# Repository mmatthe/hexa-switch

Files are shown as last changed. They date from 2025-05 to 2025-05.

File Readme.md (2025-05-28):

# HexaSwitch - 6-Channel Switch for Tasmota

This project is a custom-designed printed circuit board (PCB) for a Tasmota-compatible IoT device based on the ESP32 microcontroller. It allows switching of **6 loads**, with each channel capable of handling up to **2 Amps**. The device contains a real-time clock such that the device can also run on an independent time base. 

<p float="left">
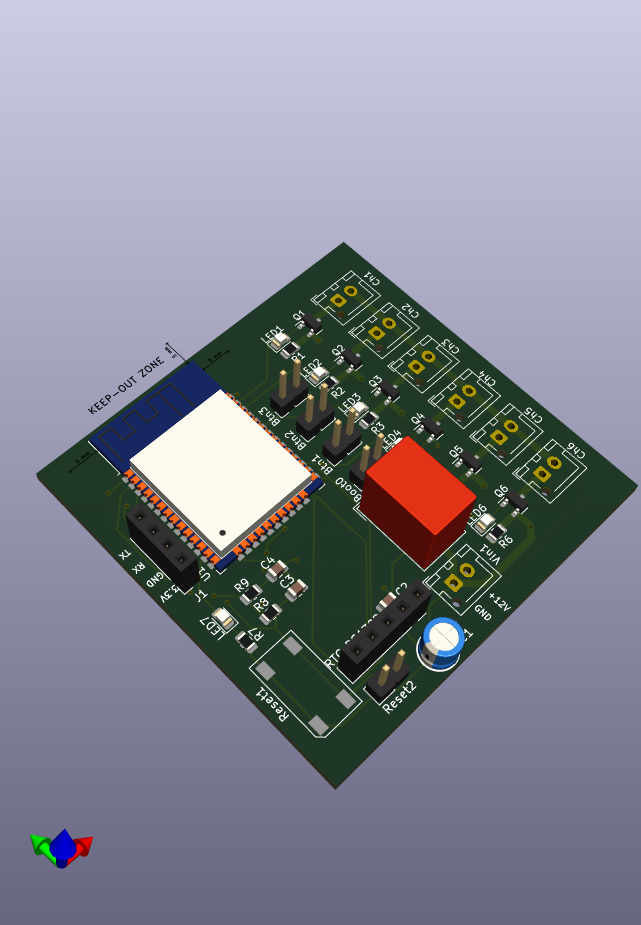
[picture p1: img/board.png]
   
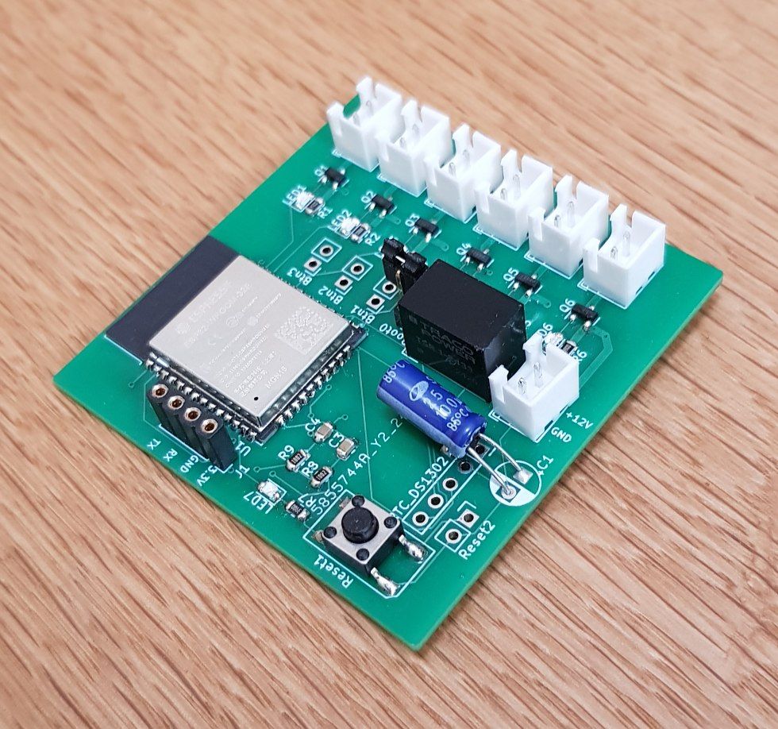
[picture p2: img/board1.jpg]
  
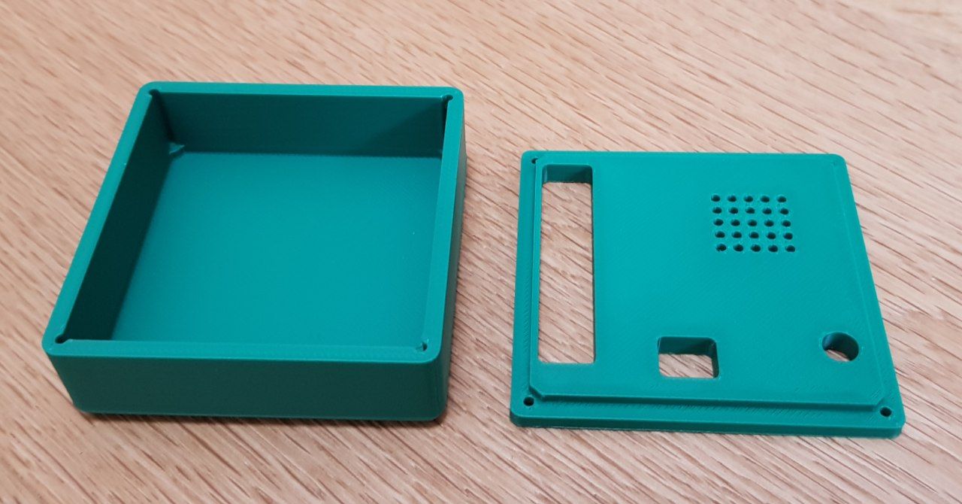
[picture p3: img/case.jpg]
   
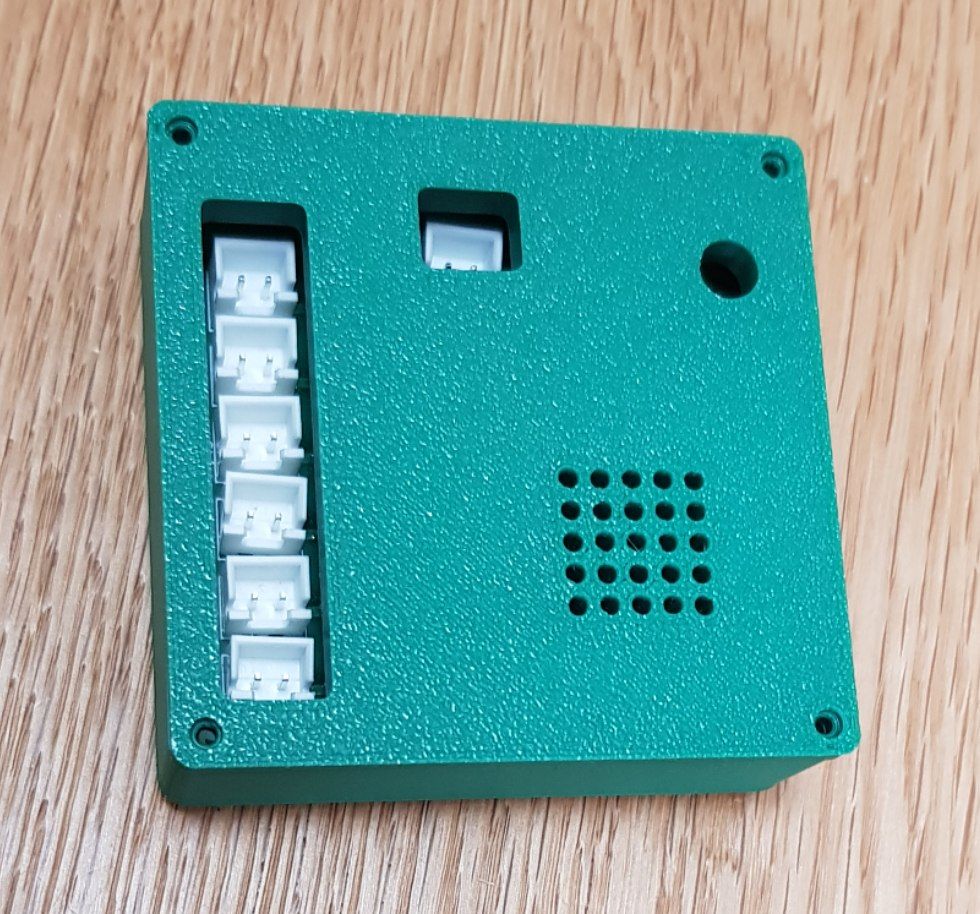
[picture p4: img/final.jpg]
   
</p>

I use it for switching on and off 12V valves for watering plants in the garden. It can also be used to switch relays and contactors to switch larger powers. 

---

## Features

- Link to [Schematic](schematic/schematic.pdf) and [BOM](schematic/bom/ibom.html)
- **ESP32-based** controller compatible with [Tasmota firmware](https://tasmota.github.io/)
- **6 independent load switching channels** (up to 2A per channel)
- **3 digital inputs**
- Supports power input from **5V to 24V**
- Optional **Real-Time Clock (RTC)** connector (not required for operation)
- Custom PCB designed using **KiCad**

---

## Hardware Details

- Power Supply: 5–24V DC input
- Switching: 6 channels, each capable of switching loads up to 2A
- Inputs: 3 digital inputs
- Microcontroller: ESP32
- Optional RTC interface for time-sensitive automation

---

## Usage

1. Assemble the PCB and connect loads to the output channels.
2. Flash the ESP32 with [Tasmota firmware](https://tasmota.github.io/).
3. Power the device with a DC supply between 5V and 24V.
4. Use Tasmota’s web interface or MQTT to control each channel independently.

---

## License

This project is released under the MIT License.

---

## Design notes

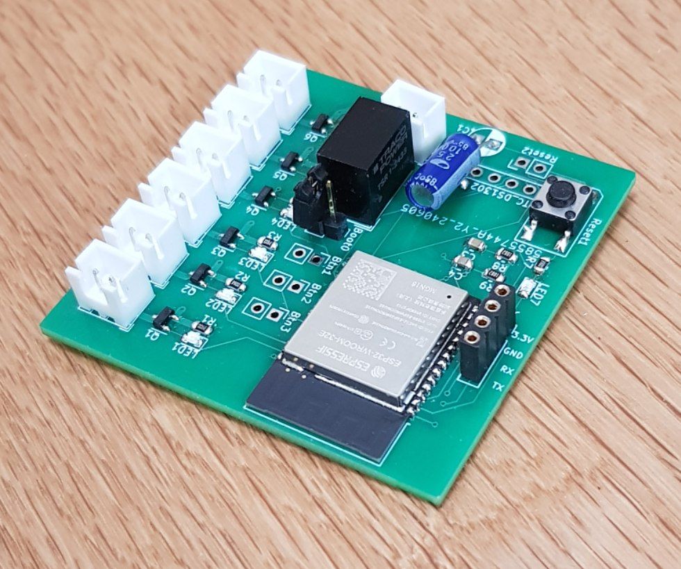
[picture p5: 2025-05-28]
img/board2.jpg

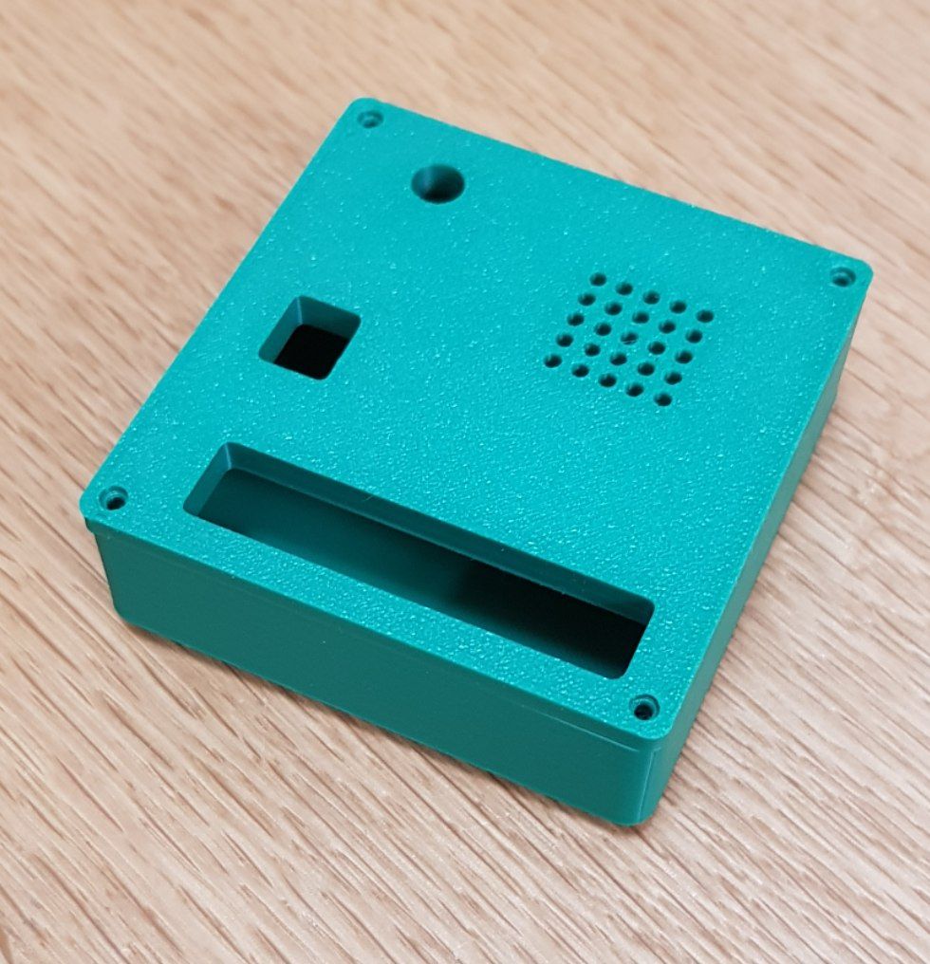
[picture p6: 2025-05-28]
img/final2.jpg

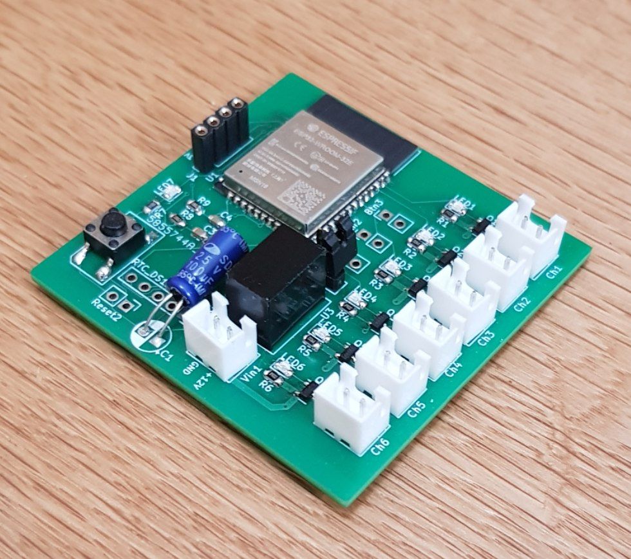
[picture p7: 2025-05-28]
img/board4.jpg

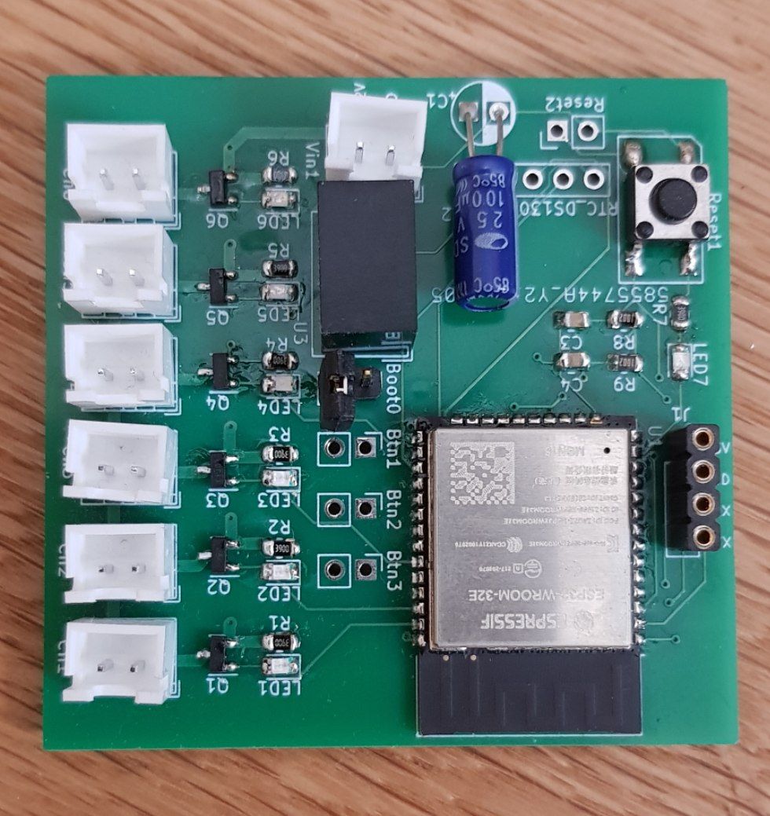
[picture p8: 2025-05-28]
img/board3.jpg

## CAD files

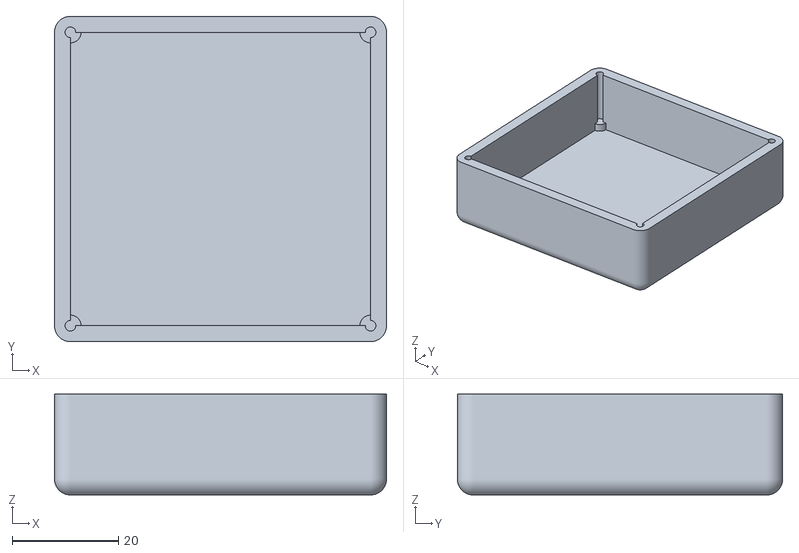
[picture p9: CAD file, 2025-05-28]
case/stl/bottom.stl
62.5 x 61.2 x 19.0

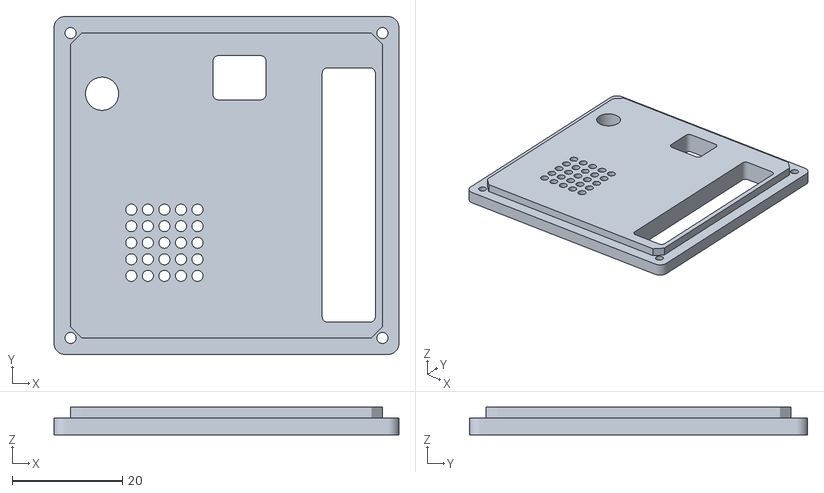
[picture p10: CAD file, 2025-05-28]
case/stl/top.stl
62.5 x 61.2 x 5.00

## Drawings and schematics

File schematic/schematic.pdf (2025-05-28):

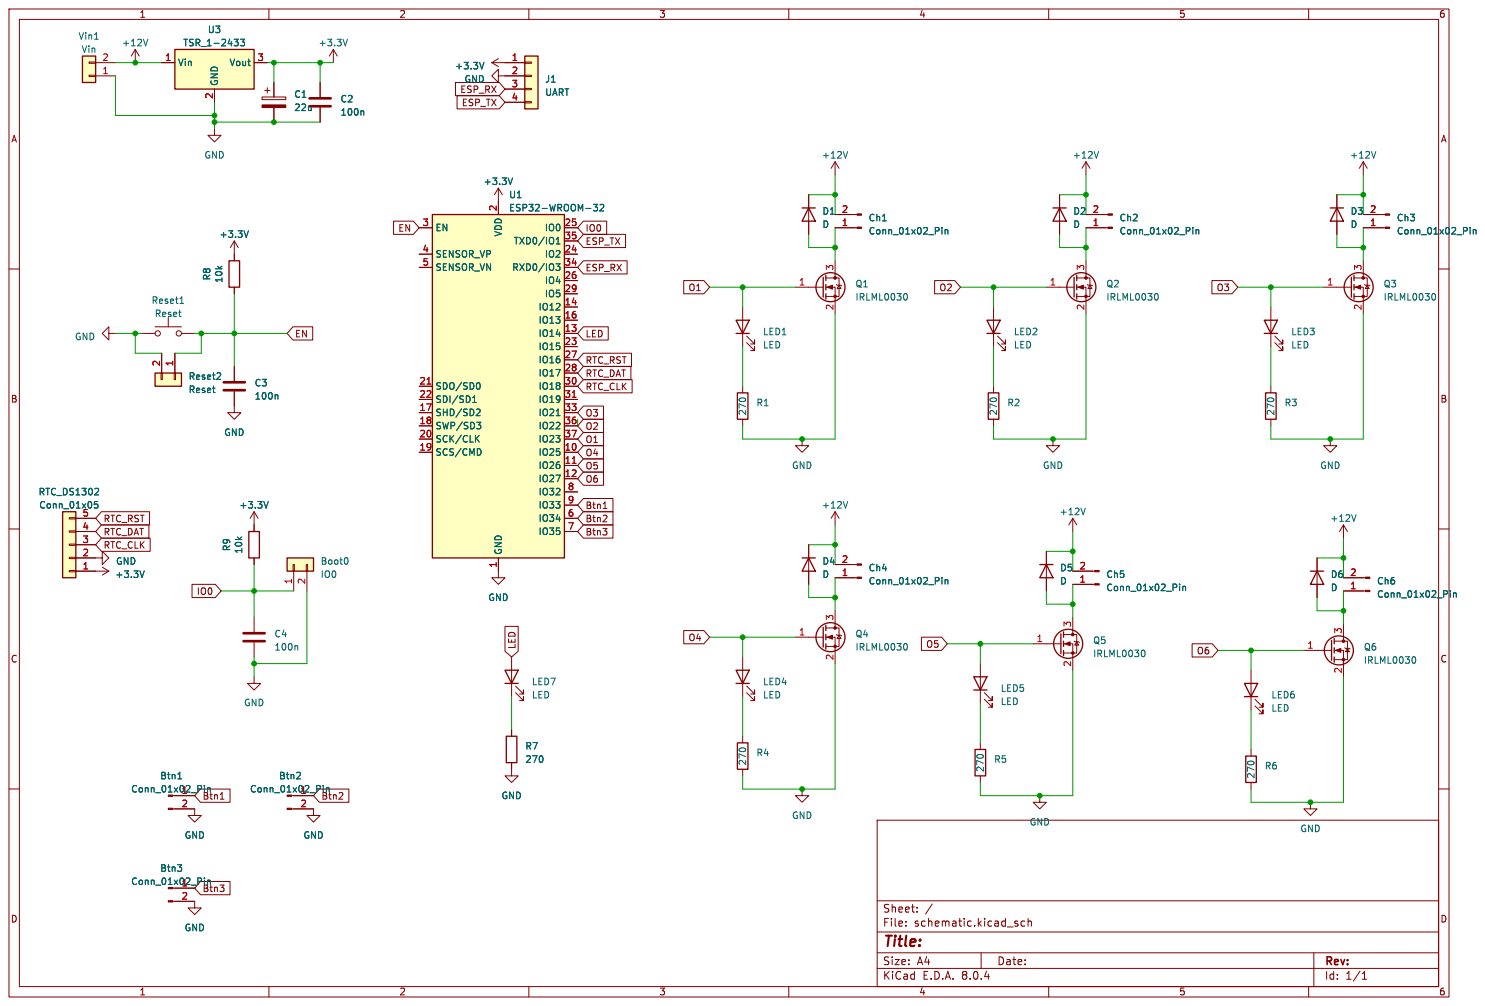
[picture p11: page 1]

2 SCK/CLK 20 SDO/SD0 21 SDI/SD1 22

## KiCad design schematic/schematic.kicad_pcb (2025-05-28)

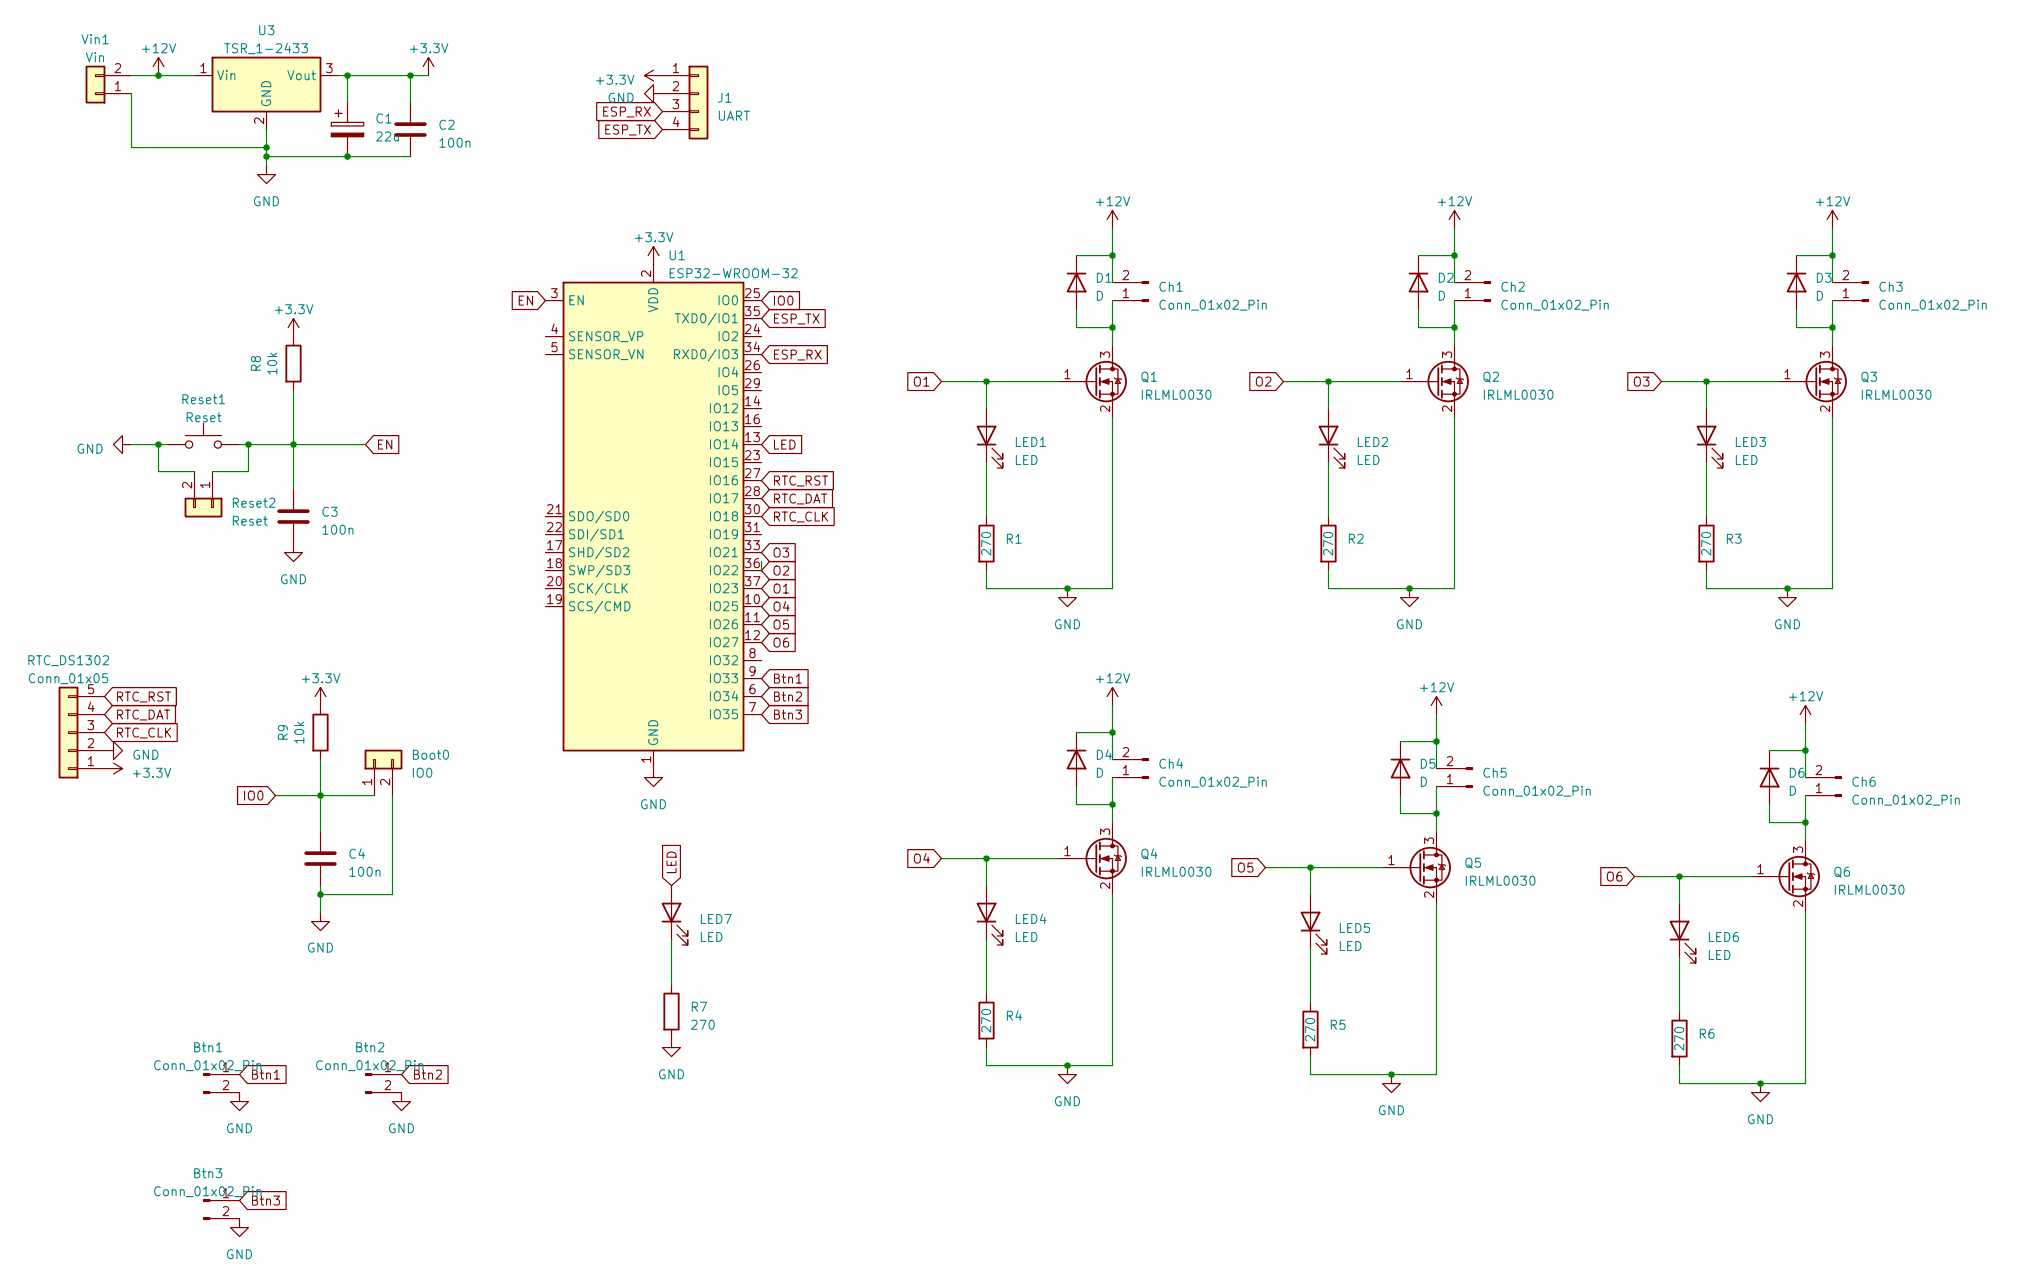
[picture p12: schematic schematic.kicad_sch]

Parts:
Boot0: IO0; PinHeader_1x02_P2.54mm_Vertical
Btn1, Btn2, Btn3: Conn_01x02_Pin; PinHeader_1x02_P2.54mm_Vertical
C1: 22u; CP_Radial_D5.0mm_P2.50mm
C2, C3, C4: 100n; C_0805_2012Metric
Ch1, Ch2, Ch3, Ch4, Ch5, Ch6: Conn_01x02_Pin; JST_XH_B2B-XH-AM_1x02_P2.50mm_Vertical
D1, D2, D3, D4, D5, D6: D; D_SOD-123
J1: UART; PinSocket_1x04_P2.54mm_Vertical
LED1, LED2, LED3, LED4, LED5, LED6, LED7: LED; LED_0805_2012Metric
Q1, Q2, Q3, Q4, Q5, Q6: IRLML0030; SOT-23
R1, R2, R3, R4, R5, R6, R7: 270; R_0805_2012Metric
R8, R9: 10k; R_0805_2012Metric
RTC_DS1302: Conn_01x05; PinSocket_1x05_P2.54mm_Vertical
Reset1: Reset; Reichelt 9315
Reset2: Reset; PinHeader_1x02_P2.54mm_Vertical
U1: ESP32-WROOM-32
U3: TSR_1-2433; Converter_DCDC_TRACO_TSR-1_THT
Vin1: Vin; JST_XH_B2B-XH-AM_1x02_P2.50mm_Vertical

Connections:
+3.3V: C1.1, C2.1, J1.1, R8.1, R9.1, RTC_DS1302.1, U1.2 (VDD), U3.3 (Vout)
+12V: Ch1.2, Ch2.2, Ch3.2, Ch4.2, Ch5.2, Ch6.2, D1.1 (K), D2.1 (K), D3.1 (K), D4.1 (K), D5.1 (K), D6.1 (K), U3.1 (Vin), Vin1.2
Btn1: Btn1.1, U1.9 (IO33)
Btn2: Btn2.1, U1.6 (IO34)
Btn3: Btn3.1, U1.7 (IO35)
EN: C3.1, R8.2, Reset1.2, Reset2.1, U1.3 (EN)
ESP_RX: J1.3, U1.34 (RXD0/IO3)
ESP_TX: J1.4, U1.35 (TXD0/IO1)
GND: Boot0.2, Btn1.2, Btn2.2, Btn3.2, C1.2, C2.2, C3.2, C4.2, J1.2, Q1.2 (S), Q2.2 (S), Q3.2 (S), Q4.2 (S), Q5.2 (S), Q6.2 (S), R1.2, R2.2, R3.2, R4.2, R5.2, R6.2, R7.2, RTC_DS1302.2, Reset1.1, Reset2.2, U1.1 (GND), U1.15 (GND), U1.38 (GND), U1.39 (GND), U3.2 (GND), Vin1.1
IO0: Boot0.1, C4.1, R9.2, U1.25 (IO0)
LED: LED7.2 (A), U1.13 (IO14)
unnamed: Ch1.1, D1.2 (A), Q1.3 (D)
unnamed: Ch2.1, D2.2 (A), Q2.3 (D)
unnamed: Ch3.1, D3.2 (A), Q3.3 (D)
unnamed: Ch4.1, D4.2 (A), Q4.3 (D)
unnamed: Ch5.1, D5.2 (A), Q5.3 (D)
unnamed: Ch6.1, D6.2 (A), Q6.3 (D)
unnamed: LED1.1 (K), R1.1
unnamed: LED2.1 (K), R2.1
unnamed: LED3.1 (K), R3.1
unnamed: LED4.1 (K), R4.1
unnamed: LED5.1 (K), R5.1
unnamed: LED6.1 (K), R6.1
unnamed: LED7.1 (K), R7.1
O1: LED1.2 (A), Q1.1 (G), U1.37 (IO23)
O2: LED2.2 (A), Q2.1 (G), U1.36 (IO22)
O3: LED3.2 (A), Q3.1 (G), U1.33 (IO21)
O4: LED4.2 (A), Q4.1 (G), U1.10 (IO25)
O5: LED5.2 (A), Q5.1 (G), U1.11 (IO26)
O6: LED6.2 (A), Q6.1 (G), U1.12 (IO27)
RTC_CLK: RTC_DS1302.3, U1.30 (IO18)
RTC_DAT: RTC_DS1302.4, U1.28 (IO17)
RTC_RST: RTC_DS1302.5, U1.27 (IO16)

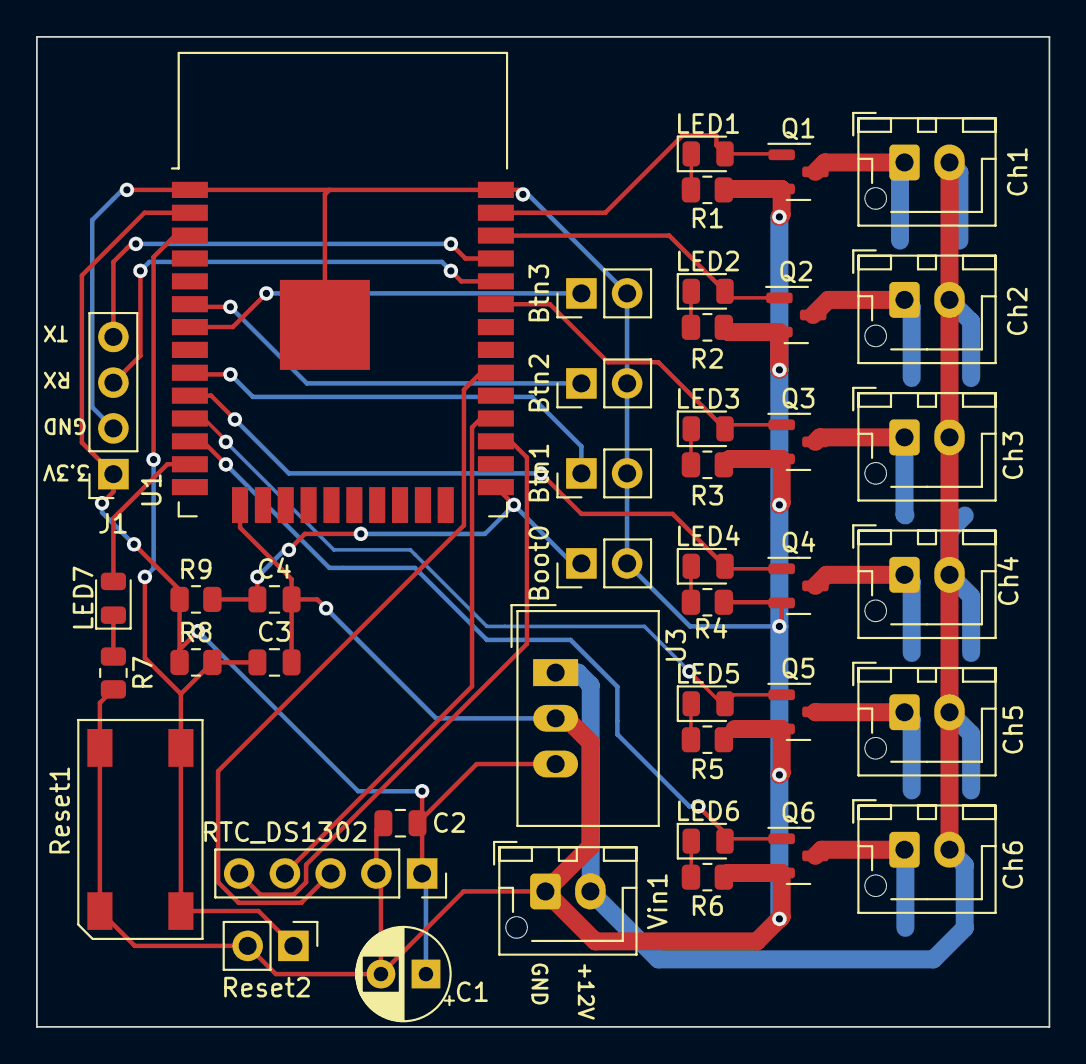
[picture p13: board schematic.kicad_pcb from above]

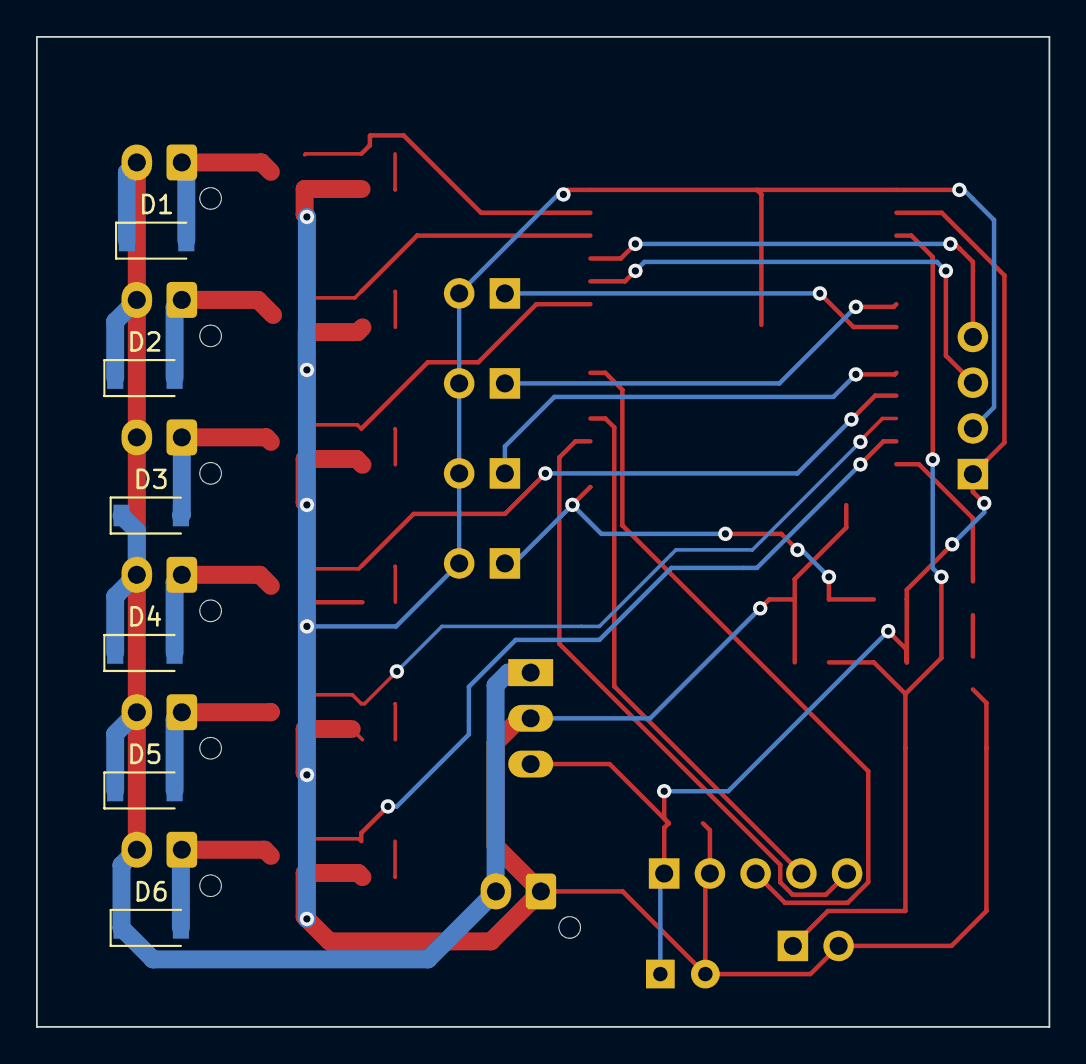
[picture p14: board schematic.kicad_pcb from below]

Board: 2 copper layers, 56.2 x 55.0 mm, 49 parts (6 on the bottom side), 33 nets.

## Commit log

2025-05-28 add readme and case
    [bottom.stl, top.stl]
2025-05-28 add schematic
    [schematic.kicad_pcb, schematic.kicad_sch]
2025-05-28 add BOM
